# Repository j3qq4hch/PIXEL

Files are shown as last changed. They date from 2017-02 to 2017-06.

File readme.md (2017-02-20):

###PIXEL###
Pixel(yet another) is a dirt cheap 10W LED constant current driver with bells and whistles. 

Two common use scenarios are:

* LED LIGHTING with digital interface(smarthome applications)
* HUGE low-res LED screens with incredible brightness
 
 The device can operate in 2 modes:
 
* As modbus slave device over RS485 non-isolated inteface. This is relative slow mode which can be used for lighting automation systems or stage light control systems.  In this mode device's clock source is external quartz oscillator and it uses UART1 for communication. 
* As shift register. In this mode device operates like three daisy-chained 595 shift registers. In this mode device's clock source is internal RC(as frequency precision is not needed) and pins PF0 PF1 are used as GPIO(for LATCH and RESET signals). More, data clock is connected to PA4, data in is PA3, data out is PA9. So, data signal appears to be buffered by MCU. Clock, latch and reset signals are buffered by external ICs, so many PIXELs can be daisy-chained without concersn about bus integrity.  

Distinguishing between these modes is mostly a matter of proper connector selection, I think.  Mode selection may be done by adding solder joint to PA3 or PA9. These pins should be sampled right after MCU reset and one of the modes should be chosen then.

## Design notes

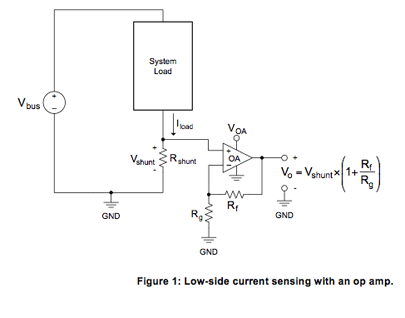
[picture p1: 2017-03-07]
doc/sense2fig1.gif

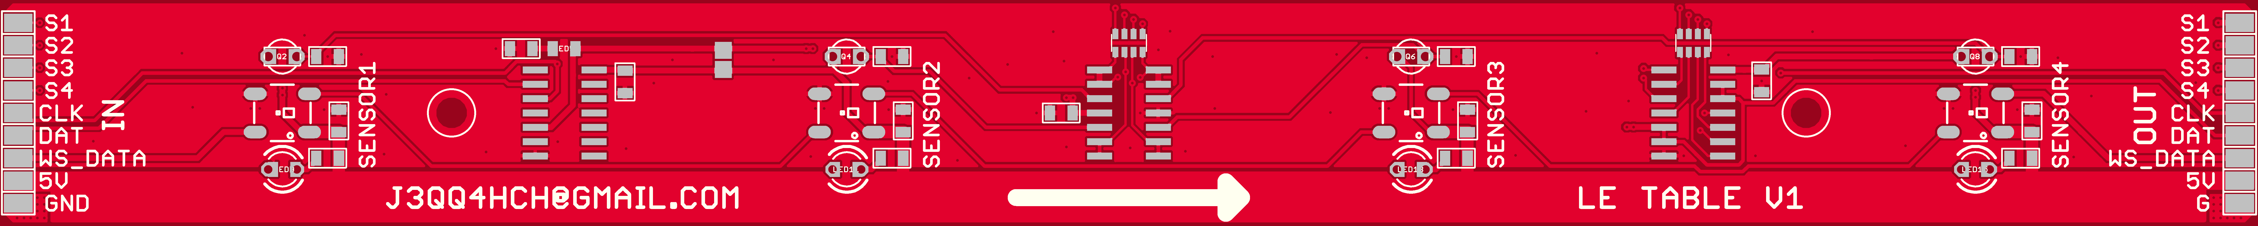
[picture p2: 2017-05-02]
LE table/eagleUp/eagleUp_le_table_board_top.png

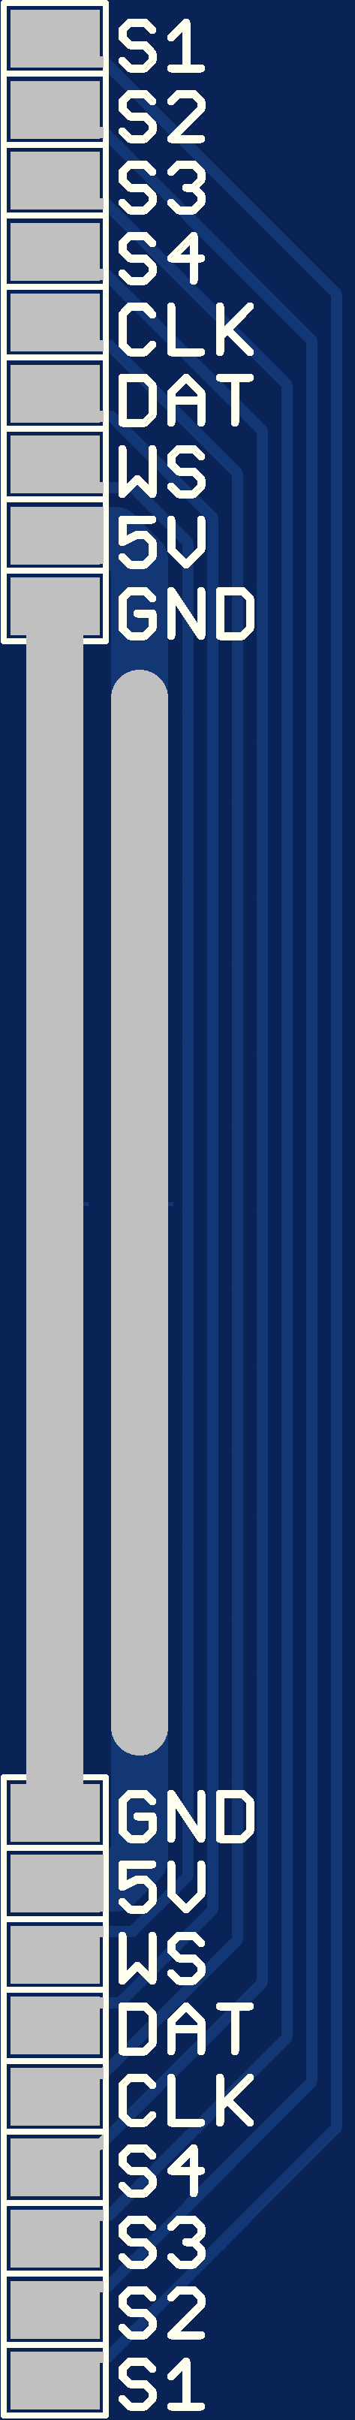
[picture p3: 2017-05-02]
LE table/eagleUp/eagleUp_CONNECTOR_board_top.png

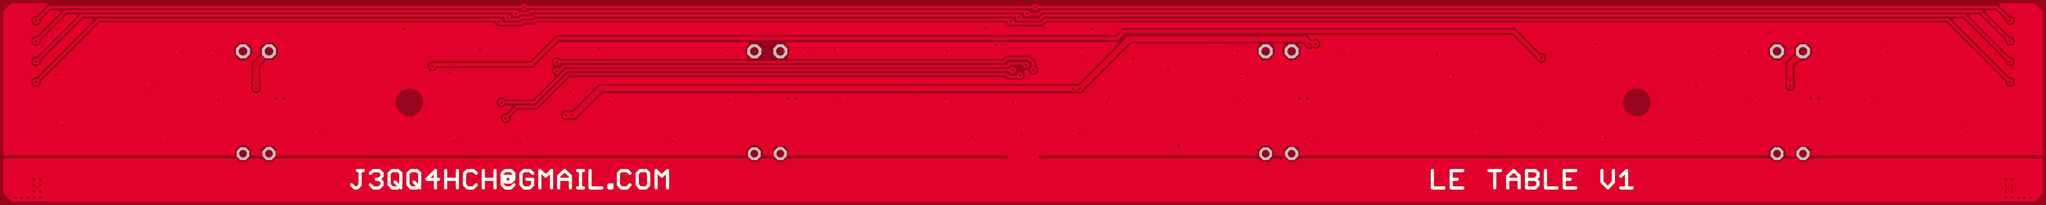
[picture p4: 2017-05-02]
LE table/eagleUp/eagleUp_le_table_board_bottom.png

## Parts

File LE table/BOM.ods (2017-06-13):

Qty | Value | Device | Package | Parts | Description | BOM | DIGIKEY# | FARNELL# | LINK | MANF | MANF# | PACKAGE | TME#
14 | 100 nF | C-0805 | C0805 | C1, C2, C3, C4, C9, C10, C11 |  |  |  | 2496834 |  |  |  | 805 | GRM188R71H104KA93D
8 | 15-24K | R-0805 | R0805 | R1, R2, R3, R4 |  |  |  |  |  |  |  | 805
10 | 150R | R-0805 | R0805 | R6, R9, R10, R11, R12 |  |  |  |  |  |  |  | 805
2 | 150R | RESISTOR_ARRAY | CAT16-J4 | RN2 | Chip Resistor Array 4 Single Resistor
2 | 2N7002 (https://www.chipdip.ru/product/2n7002-2) | 2N7002 (https://www.chipdip.ru/product/2n7002-2) | SOT23B-3 | Q9 |  |  | IRLML2502PBFTR-ND |  |  | Infineon Technologies | IRLML2502TRPBF
2 | LM2902DT | LM2902DT | SO-14 | IC1 |  |  |  |  | https://www.chipdip.ru/product/lm2902dt-2
2 | M74HCT74 | M74HCT74 | SO-14 | IC3 |  |  |  |  | https://www.chipdip.ru/product/m74hct74rm1
2 | CD4066 | CD4066 | SO-14 | IC2 |  |  |  |  | https://www.chipdip.ru/product/cd4066bm
8 | WS2812B | WS2812B | WS2812B | LED1, LED2, LED3, LED4
8 | LED-0805 | LED-0805 | 1206 LED | LED9, LED11, LED13, LED15 | IR led |  |  |  |  |  |  | 805
8 | PHOTOTRANSISTOR-1206 | PHOTOTRANSISTOR-1206 | 1206 | Q2, Q4, Q6, Q8

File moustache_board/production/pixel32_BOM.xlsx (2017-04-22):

Qty | Value | Parts | Description | Package | Manufacturer | Manufacturer part number | Chip & Dip | DigiKey | Farnell | TME
2 | 10 pF | C19, C20 | SMD Capacitor, ± 5%, C0G / NP0 | 0603 | Any | Any |  |  | 1414601 | GRM1885C1H100JA01D
1 | 10 nF | C15 | SMD Capacitor, ± 10%, 6.3V or greater | 0603 | Any | Any |  |  | 2496827 | C0603C103K3RAC
10 | 100 nF | C13, C17, C18, C21, C23, C24, C26, C103, C203, C303 | SMD Capacitor, ± 10%, 50V or greater | 0603 | Any | Any |  |  | 2496834 | GRM188R71H104KA93D
2 | 100 nF | C5, C6 | SMD Capacitor, ± 10%, 50V or greater | 0805 | Any | Any |  |  | 499687
1 | 1 uF | C14 | SMD Capacitor, ± 10%, 6.3V or greater | 0603 | Any | Any |  |  | 2496917 | GRM188R61C105KA93D
3 | 1 uF | C102, C202, C302 | SMD Capacitor, ± 10%, 50V or greater | 0805 | Any | Any |  |  | 1735541 | GRM21BR71H105KA12K
4 | 4.7 uF | C3, C4, C16 | SMD Capacitor, ± 10%, 6.3V or greater | 0603 | Any | Any |  |  | 2496930 | GRM188R60J475KE19D
4 | 10 uF | C101, C201, C301 | SMD Capacitor, ± 10%, 50V or greater | 1812 | Any | Any |  |  | 2449143 | CL32B106KBJNNNE
3 | 2R | R102, R202, R302 | SMD Chip Resistor, ±1%, 250 mW | 1206 | Any | Any |  |  | 2328120 | RC1206FR-072R
6 | 22R | R101, R103, R201, R203, R301, R303 | SMD Chip Resistor, ±1% | 0603 | Any | Any |  |  | 2302996 | CRCW060322R0FKEA
2 | 100R | R11, R12 | SMD Chip Resistor, ±1% | 0603 | Any | Any |  |  | 2303059 | RC0603FR-07100R
1 | 120R | R5 | SMD Chip Resistor, ±1% | 0603 | Any | Any |  |  | 2303067 | CRCW0603120RFKTABC
2 | 1K | R6, R39 | SMD Chip Resistor, ±1% | 0603 | Any | Any |  |  | 2303145 | RC0603FR-071K
1 | 1K6 | R7 | SMD Chip Resistor, ±1% | 0603 | Any | Any |  |  | 2303159 | RC0603FR-071K6
6 | 10K | R3, R8, R9, R13, R14, R15 | SMD Chip Resistor, ±1% | 0603 | Any | Any |  |  | 2008341 | RC0603FR-0710K
1 | 100K | R10 | SMD Chip Resistor, ±1% | 0603 | Any | Any |  |  | 2303232 | RC0603FR-07100K
1 | 115K | R2 of MODULE1 | SMD Chip Resistor, ±1% | 0603 | Any | Any |  |  | 2303234 | N/A
2 | 510R | RN1, RN2 | Chip Resistor Array 4 Single Resistor | CAT16-J4 | Bourns Inc | CAT16-511J4LF | 9000044911 | CAT16-511J4LF-ND | 2321730 | N/A
3 | 47 uH | L102, L202, L302 | Unshielded Wirewound Inductor, 1 A RMS max, 1.6 A saturation, 0.2 ohm | SDR0805 | Bourns Inc | SDR0805-470KL | 8980699057 | SDR0805-470KLCT-ND | 1828030 | N/A
1 | 16MHz | Y1 | SMD Crystal, 10 ppm, 9 pF | 3.2X2.5 | Epson | X1E0000210013 TSX-3225 16 MHZ 9.0PF | 8596067027 | SER4069CT-ND | 1712841 | N/A
1 | LED-0603 | LED2 | SMD LED, Green, 20 mA, 2.1 V | LED0603 | Lite-On Inc | LTST-C191KGKT | 8598509892 | 160-1446-1-ND | 2293494 | LTST-C191KGKT
3 | DIODE-SOD123 | D101, D201, D301 | Schottky Rectifier, 100 V, 1 A | SOD123 | ON Semiconductor | MBRS1100T3G | MBRS1100T3G | MBRS1100T3GOSCT-ND | 9555862 | MBRS1100T3G
1 | SMF05C | D1 | 5 TVS Diode Array, Unidirectional, 5V Vrwm, 12.5 Vc Max | SC70_6L | Semtech Corporation | SMF05C.TCT | 9000048448 | SMF05CCT-ND | 2059033 | SMF05CT1G
1 | TVS_DIODE-SMB | D5 | TVS Diode, Unidirectional, 26V Vrwm, 53.5 Vc Max | SMB | STMicroelectronics | SMBJ26CA | 8023193826 | 497-15658-2-ND | 1749366 | SMBJ26CA-LF
3 | N-FET-SOT23 | Q101, Q201, Q301 | MOSFET Transistor, N Channel, 3.6 A, 40 V, 0.044 ohm | SOT23-3 | Infineon Technologies | IRLML0040TRPBF | 9000095041 | IRLML0040TRPBFCT-ND | 1831088 | IRLML0040TRPBF
1 | GW1584 | MODULE1 | http://mysku.ru/blog/aliexpress/35938.html | GW1584 | Unknown | GW1584 | N/A | N/A | N/A | N/A
3 | IRS44273L | IC101, IC201, IC301 | Low-Side Gate Driver IC Non-Inverting SOT-23-5 | SOT23-5 | Infineon Technologies | IRS44273LTRPBF | 9000204261 | IRS44273LTRPBFTR-ND | 2580779 | IRS44273LTRPBF
1 | STM32F030K6TX-LQFP32(7X7) | IC1 | ARM® Cortex®-M0 STM32 F0 Microcontroller IC 32-Bit 48MHz 32KB (32K x 8) FLASH | LQFP32 | STMicroelectronics | STM32F030K6T6 | 9000250493 | 497-14046-ND | 2432085 | STM32F030K6T6
1 | ST3485SOIC8 | IC3 | 1/1 Transceiver Half RS422, RS485 | SOIC8 | STMicroelectronics | ST3485EBDR | 9000220421 | 497-2080-1-ND | 2253266 | ST3485EBD
2 | MC74VHC1GT125 | IC6, IC7 | Buffer, Non-Inverting 1 Element 1 Bit per Element Push-Pull Output | SOT23-5 | ON Semiconductor | MC74VHC1GT125 | 9000014391 | MC74VHC1GT125DT1GOSDKR-ND | 2101847 | N/A
1 | LM317 | IC8 | Linear Voltage Regulator IC Positive Adjustable Output 1.25 V ~ 37 V 1.5A | SOT223 | Texas Instruments | LM317MSTT3G | LM317DCY | 296-23224-5-ND | 2112605 | LM317DCY
2 | B7B-PH-K-S-SIDE | CON1, CON2 | 7 Positions Header Connector, Through Hole | 2.00 mm x 7 | JST or Confly | B7B-PH-K-S(LF)(SN) or DS1066-08M(MW-8M) | 9000325604 | 455-1709-ND | 9491864 | B7B-PH-K-S
2 | PINHEAD_1X02-2.54 | СON3 | pinheader 2P | 1X02-PTH-2.54 | Any

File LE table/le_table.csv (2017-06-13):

Qty | Value | Device | Package | Parts | Description | BOM | DIGIKEY# | FARNELL# | LINK | MANF | MANF# | PACKAGE | TME#
2 |  | SOLDER_JOINT | RES_0 | SJ1, SJ2
7 | 100 nF | C-0805 | C0805 | C1, C2, C3, C4, C9, C10, C11 |  |  |  | 2496834 |  |  |  | 0805 | GRM188R71H104KA93D
4 | 15-20K | R-0805 | R0805 | R1, R2, R3, R4 |  |  |  |  |  |  |  | 0805
5 | 150R | R-0805 | R0805 | R6, R9, R10, R11, R12 |  |  |  |  |  |  |  | 0805
1 | 150R | RESISTOR_ARRAY | CAT16-J4 | RN2 | Chip Resistor Array 4 Single Resistor
1 | 2K | R-0805 | R0805 | R5 |  |  |  |  |  |  |  | 0805
1 | CD4066 | CD4066 | SO-14 | IC2 |  |  |  |  | https://www.chipdip.ru/product/cd4066bm
3 | CONNECTION | CONNECTION | CONNECTION | U$3, U$6, U$7 |  | EXCLUDE
2 | CONNECTOR | CONNECTOR | CONNECTOR | CON2, CON5 |  | EXCLUDE
1 | IRLML2502-SOT23 | IRLML2502-SOT23 | SOT23B-3 | Q9 | MOSFET N-CH 20V 4.2A SOT-23 |  | IRLML2502PBFTR-ND |  |  | Infineon Technologies | IRLML2502TRPBF
5 | LED-0805 | LED-0805 | 0805_LED | LED5, LED9, LED11, LED13, LED15 |  |  |  |  |  |  |  | 0805
1 | LM2902DT | LM2902DT | SO-14 | IC1 |  |  |  |  | https://www.chipdip.ru/product/lm2902dt-2
1 | M74HCT74 | M74HCT74 | SO-14 | IC3 |  |  |  |  | https://www.chipdip.ru/product/m74hct74rm1
4 | PHOTOTRANSISTOR-0805 | PHOTOTRANSISTOR-0805 | 0805 | Q2, Q4, Q6, Q8
2 | PINHEAD_1X09-2 | PINHEAD_1X09-2 | 1X09-PTH_2 | CON3, CON4 |  | EXCLUDE
4 | WS2812B | WS2812B | WS2812B | LED1, LED2, LED3, LED4

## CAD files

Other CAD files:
LE table/PCB.skp
LE table/connector.skp
LE table/table.skp

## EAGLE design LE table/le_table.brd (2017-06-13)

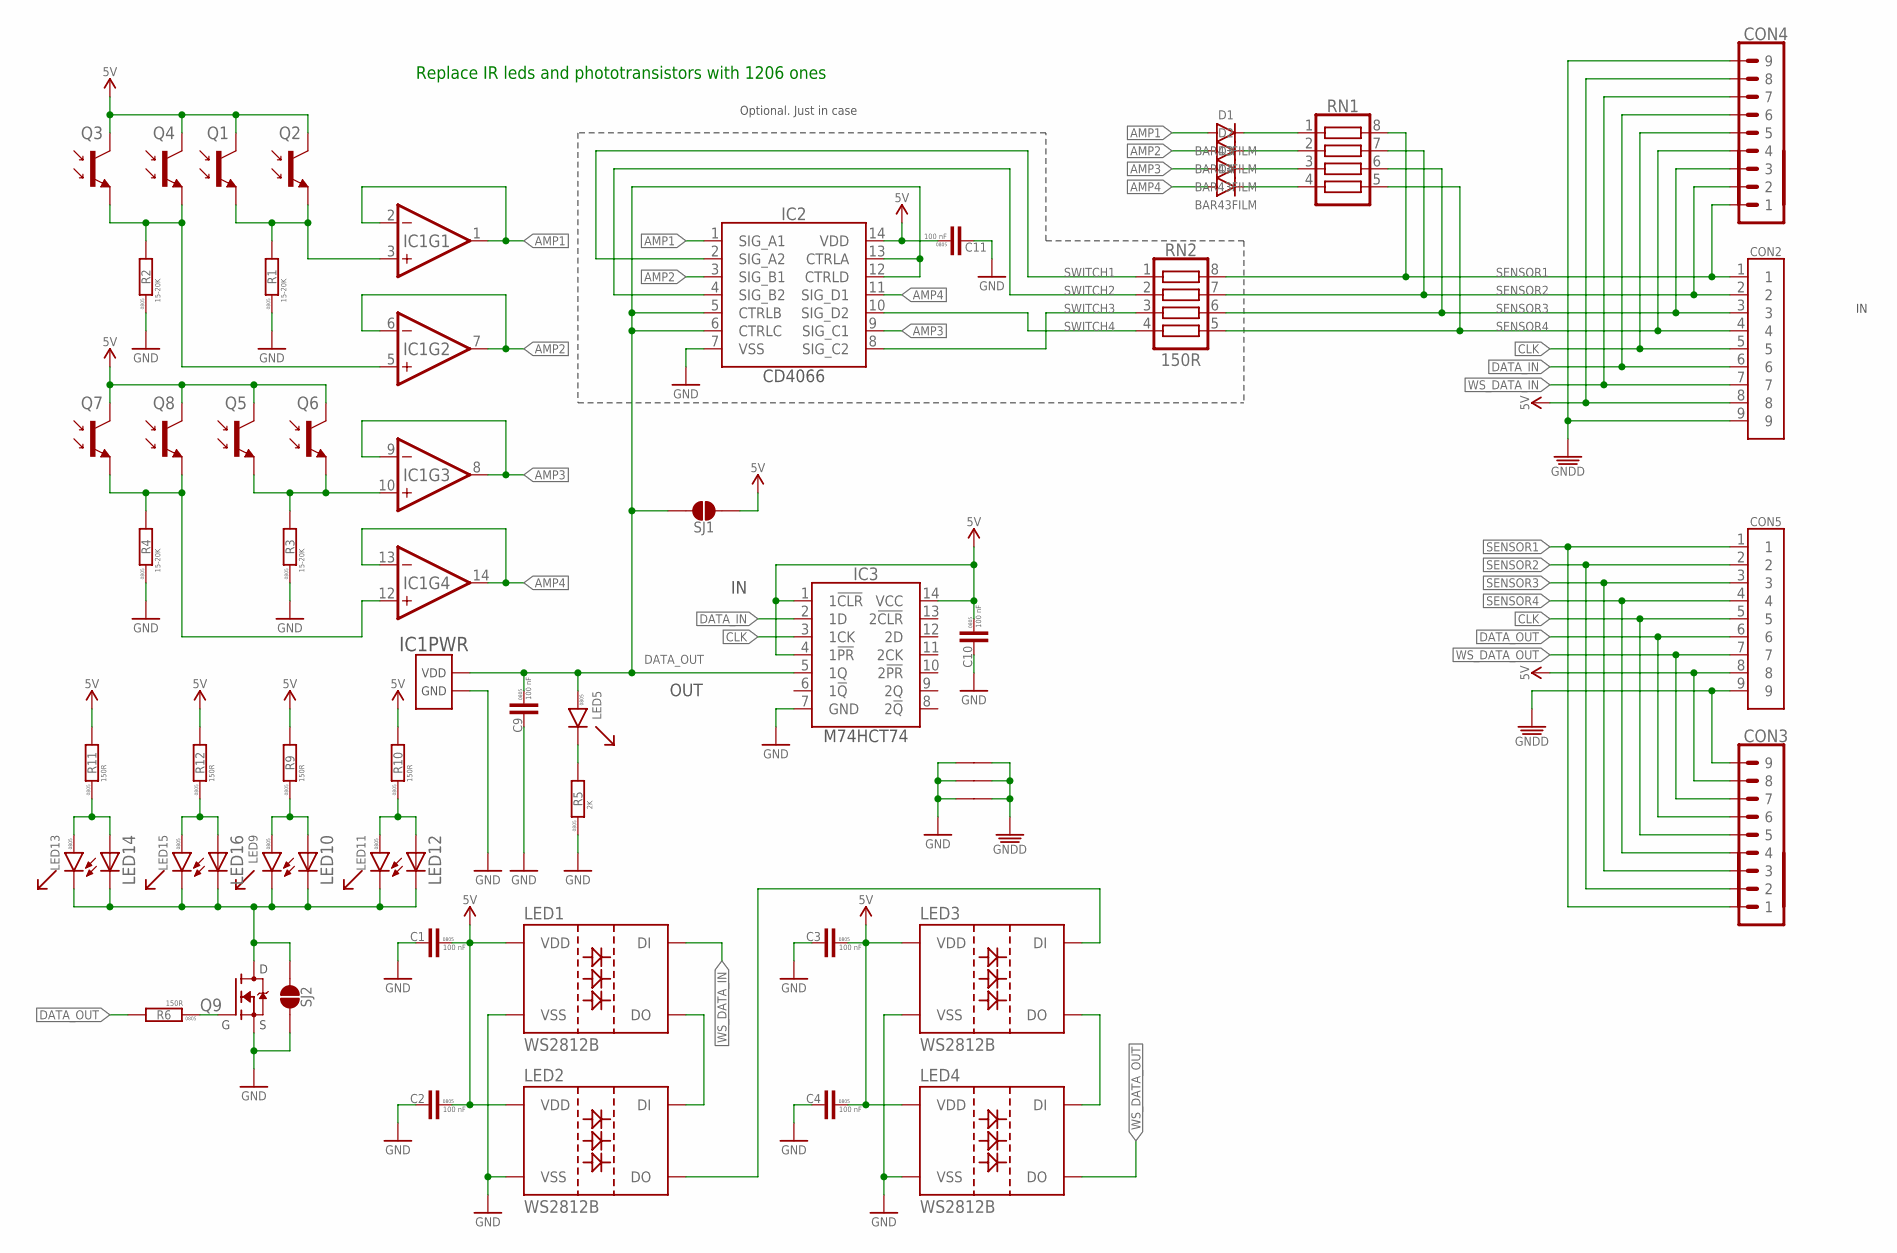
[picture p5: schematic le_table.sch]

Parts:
C1, C2, C3, C4, C9, C10, C11: 100 nF; C0805; FARNELL# 2496834
CON2, CON5: CONNECTOR
CON3, CON4: PINHEAD_1X09-2; 1X09-PTH_2
D1, D2, D3, D4: BAR43AFILM; SOT23-3
IC1: LM2902DT; SO-14
IC2: CD4066; SO-14
IC3: M74HCT74; SO-14
LED1, LED2, LED3, LED4: WS2812B
LED5, LED9, LED11, LED13, LED15: LED-0805; 0805_LED
LED10, LED12, LED14, LED16: LED-3MM
Q1, Q3, Q5, Q7: PHOTOTRANSISTOR-3MM; LED-3MM
Q2, Q4, Q6, Q8: PHOTOTRANSISTOR-0805; 0805
Q9: IRLML2502-SOT23; SOT23B-3
R1, R2, R3, R4: 15-20K; R0805
R5: 2K; R0805
R6, R9, R10, R11, R12: 150R; R0805
RN1: RESISTOR_ARRAY; CAT16-J4
RN2: 150R; CAT16-J4
SJ1, SJ2: SOLDER_JOINT; RES_0
U$3, U$6, U$7: CONNECTION

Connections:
AMP1: D1.1 (A), IC1.1 (OUT), IC1.2 (-IN), IC2.1 (SIG_A1)
AMP2: D2.1 (A), IC1.6 (-IN), IC1.7 (OUT), IC2.3 (SIG_B1)
AMP3: D3.1 (A), IC1.8 (OUT), IC1.9 (-IN), IC2.9 (SIG_C1)
AMP4: D4.1 (A), IC1.13 (-IN), IC1.14 (OUT), IC2.11 (SIG_D1)
CLK: CON2.5, CON3.5, CON4.5, CON5.5, IC3.3 (1CK)
DATA_IN: CON2.6, CON4.6, IC3.2 (1D)
DATA_OUT: C9.1, CON3.6, CON5.6, IC1.4 (VDD), IC2.5 (CTRLB), IC2.6 (CTRLC), IC2.12 (CTRLD), IC2.13 (CTRLA), IC3.5 (1Q), LED5.A, R6.2, SJ1.2
GND: C1.2, C2.2, C3.2, C4.2, C9.2, C10.2, C11.2, IC1.11 (GND), IC2.7 (VSS), IC3.7 (GND), LED1.3 (VSS), LED2.3 (VSS), LED3.3 (VSS), LED4.3 (VSS), Q9.2 (S), R1.1, R2.1, R3.1, R4.1, R5.1, SJ2.2, U$3.P$2, U$6.P$2, U$7.P$2
GNDD: CON2.9, CON3.9, CON4.9, CON5.9, U$3.P$1, U$6.P$1, U$7.P$1
unnamed: Q9.1 (G), R6.1
unnamed: LED5.C, R5.2
unnamed: LED1.2 (DO), LED2.4 (DI)
unnamed: LED2.2 (DO), LED3.4 (DI)
unnamed: LED3.2 (DO), LED4.4 (DI)
unnamed: LED11.A, LED12.A, R10.1
unnamed: LED13.A, LED14.A, R11.1
unnamed: LED9.A, LED10.A, R9.1
unnamed: LED15.A, LED16.A, R12.1
unnamed: D1.3 (C), RN1.1
unnamed: D2.3 (C), RN1.2
unnamed: D3.3 (C), RN1.3
unnamed: D4.3 (C), RN1.4
unnamed: LED9.C, LED10.K (C), LED11.C, LED12.K (C), LED13.C, LED14.K (C), LED15.C, LED16.K (C), Q9.3 (D), SJ2.1
SENS1: IC1.3 (+IN), Q1.K (E), Q2.2 (E), R1.2
SENS2: IC1.5 (+IN), Q3.K (E), Q4.2 (E), R2.2
SENS3: IC1.10 (+IN), Q5.K (E), Q6.2 (E), R3.2
SENS4: IC1.12 (+IN), Q7.K (E), Q8.2 (E), R4.2
SENSOR1: CON2.1, CON3.1, CON4.1, CON5.1, RN1.8, RN2.8
SENSOR2: CON2.2, CON3.2, CON4.2, CON5.2, RN1.7, RN2.7
SENSOR3: CON2.3, CON3.3, CON4.3, CON5.3, RN1.6, RN2.6
SENSOR4: CON2.4, CON3.4, CON4.4, CON5.4, RN1.5, RN2.5
SWITCH1: IC2.2 (SIG_A2), RN2.1
SWITCH2: IC2.4 (SIG_B2), RN2.2
SWITCH3: IC2.8 (SIG_C2), RN2.3
SWITCH4: IC2.10 (SIG_D2), RN2.4
VDD_5V: C1.1, C2.1, C3.1, C4.1, C10.1, C11.1, CON2.8, CON3.8, CON4.8, CON5.8, IC2.14 (VDD), IC3.1 (1!CLR), IC3.4 (1!PR), IC3.14 (VCC), LED1.1 (VDD), LED2.1 (VDD), LED3.1 (VDD), LED4.1 (VDD), Q1.A (C), Q2.1 (C), Q3.A (C), Q4.1 (C), Q5.A (C), Q6.1 (C), Q7.A (C), Q8.1 (C), R9.2, R10.2, R11.2, R12.2, SJ1.1
WS_DATA_IN: CON2.7, CON4.7, LED1.4 (DI)
WS_DATA_OUT: CON3.7, CON5.7, LED4.2 (DO)

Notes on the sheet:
OUT
Optional. Just in case
Replace IR leds and phototransistors with 1206 ones

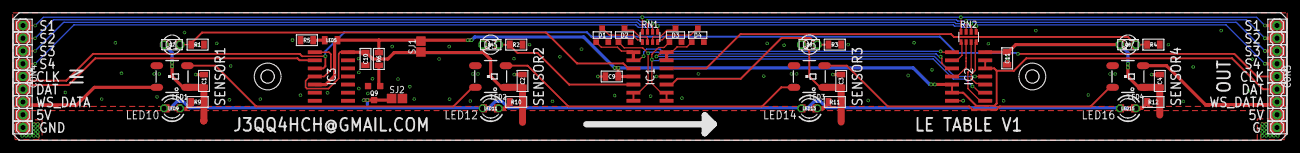
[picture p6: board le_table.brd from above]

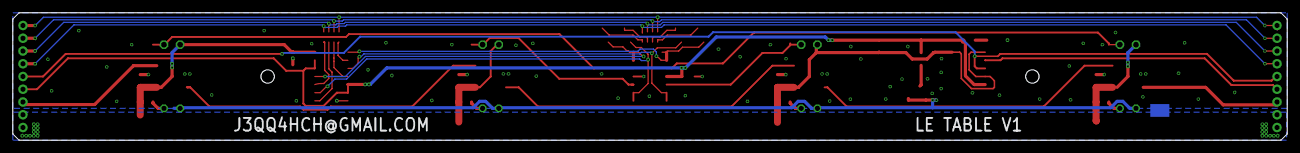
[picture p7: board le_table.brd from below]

Board: 2 copper layers, 200.0 x 20.0 mm, 59 parts (3 on the bottom side), 38 nets.

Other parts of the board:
U$1, U$4: MOUNTING_HOLE_M2

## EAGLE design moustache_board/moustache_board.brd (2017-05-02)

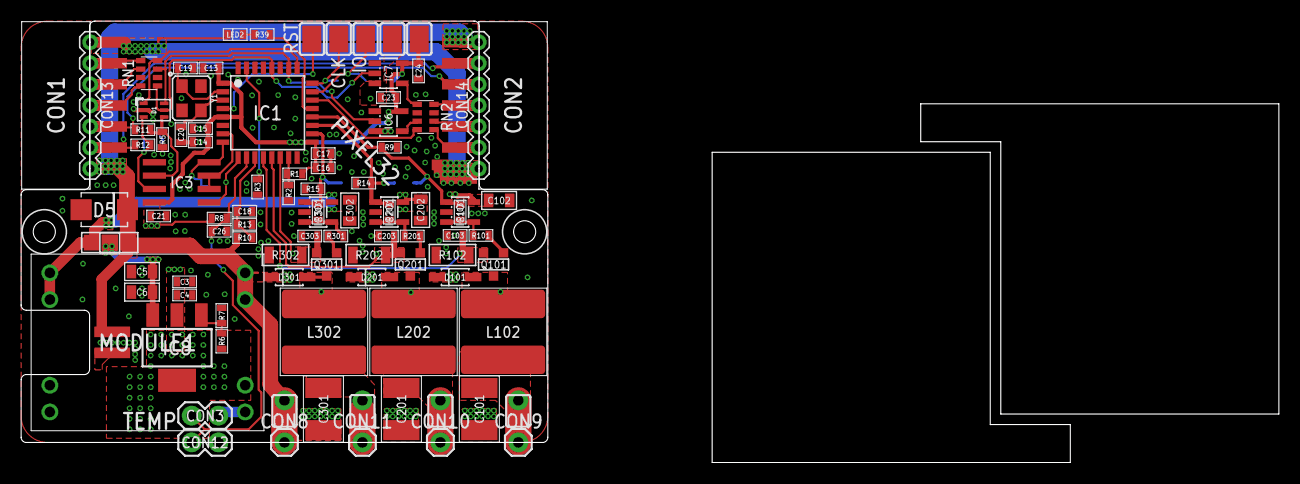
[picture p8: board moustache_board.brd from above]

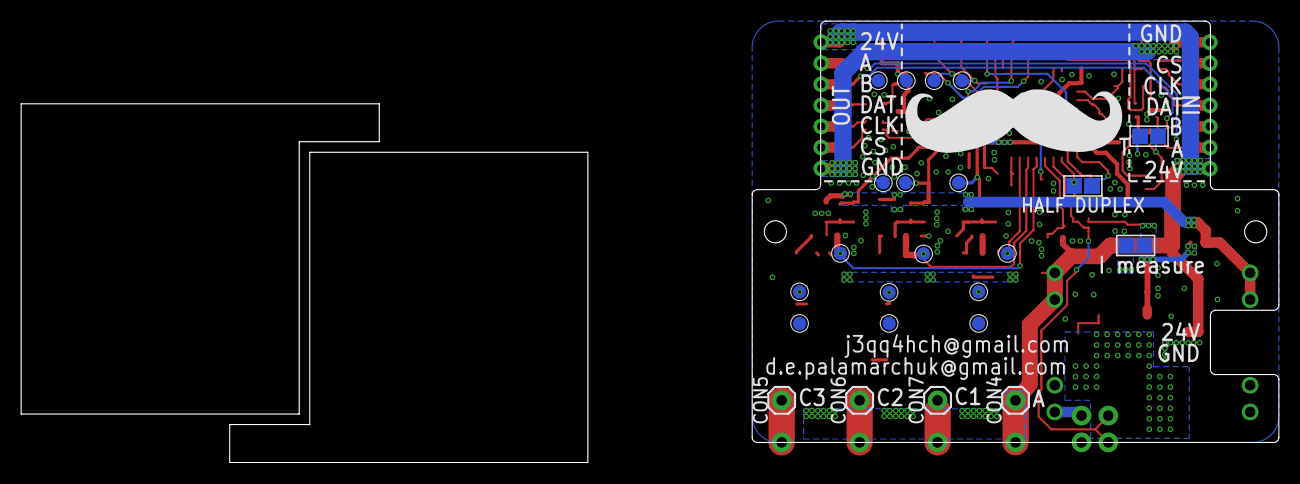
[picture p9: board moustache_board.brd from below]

Board: 2 copper layers, 50.0 x 40.0 mm, 129 parts (24 on the bottom side), 57 nets.

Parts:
C3, C4, C16: 4.7 uF; C0603
C5, C6: 100 nF; C0805
C13, C17, C18, C21, C23, C24, C26, C103, C203, C303: 100 nF; C0603
C14: 1 uF; C0603
C15: 10 nF; C0603
C19, C20: 10 pF; C0603
C101, C201, C301: 10 uF; C1812
C102, C202, C302: 1 uF; C0805
CON1, CON2: B7B-PH-K-S-SIDE; B7B-PH-K-S_SIDE
CON3, CON12: PINHEAD_1X02-2.54; 1X02-PTH-2.54
CON4, CON5, CON6, CON7, CON8, CON9, CON10, CON11: PINHEAD_1X01-2.54; 1X01-PTH-2.54
CON13, CON14: PINHEAD_1X07-2; 1X07-PTH-2
CON15: B2B-PH-K-S_SIDE_MOUNT
D1: SMF05C; SC70_6L
D5: TVS_DIODE-SMB; SMB
D101, D201, D301: DIODE-SOD123; SOD123
DRILEGEND: DRILEGEND
IC1: STM32F030K6TX-LQFP32(7X7); LQFP32-7X7
IC3: ST3485SOIC8; SOIC8
IC6, IC7: MC74VHC1GT125; SOT23-5
IC8: LM317; SOT223
IC101, IC201, IC301: IRS44273L; SOT23-5
L102, L202, L302: 47UH; SDR0805
LED2: LED-0603; LED0603
LED_ANODE: WIREPADSMD2.5-1.8; PAD-2.5-1.8
LED_CATHODE1, LED_CATHODE2, LED_CATHODE3: WIREPADSMD2.5-1.8; PAD-2.5-1.8
MODULE1: GW1584
PAD1, PAD2, PAD3, PAD4, PAD5: WIREPADSMD2.5-1.8; PAD-2.5-1.8
Q101, Q201, Q301: N-FET-SOT23; SOT23-3
R1, R2, R11, R12: 100R; R0603
R3, R8, R9, R13, R14, R15: 10K; R0603
R5: 120R; R0603
R6, R39: 1K; R0603
R7: 1K6; R0603
R10: 100K; R0603
R101, R103, R201, R203, R301, R303: 22R; R0603
R102, R202, R302: 2R; R1206
RN1, RN2: 510R; CAT16-J4
SJ1, SJ2, SJ3, SJ4, SJ5: RES_0
TP1, TP2, TP3, TP4, TP101, TP102, TP103, TP104, TP201, TP202, TP203, TP204, TP301, TP302, TP303, TP304: PAD.05; PAD.05X.05
U$2: BOARD_OUTLINE
U$3, U$6, U$7, U$8, U$9, U$10: CONNECTION
U$4, U$5: MOUNTING_HOLE_M2
U$11: MOUSTACHE2
Y1: 16MHz; OSCILLATOR-3.2X2.5

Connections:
A: D1.4, IC3.6, R5.2, R11.1
B: D1.3, IC3.7, R12.1, SJ2.1
CLOCK: D1.6, IC1.26, IC6.2, RN1.3
CLOCK_BUFFERED: IC6.4, RN2.3
CS: D1.1, IC1.25, RN1.4
CS_OUT: IC1.22, RN2.4
DATA_BUFFERED: IC7.4, RN2.1
GND: C3.1, C4.1, C5.1, C6.1, C13.1, C14.1, C15.1, C16.1, C17.1, C18.1, C19.2, C20.2, C21.1, C23.1, C24.1, C26.1, C102.1, C103.1, C202.1, C203.1, C302.1, C303.1, CON3.1, CON12.1, CON15.1, D1.2, D5.A, IC1.16, IC1.32, IC3.5, IC6.3, IC7.3, IC101.2, IC201.2, IC301.2, MODULE1.IN-@1, MODULE1.IN-@2, MODULE1.OUT-@1, MODULE1.OUT-@2, PAD4.P$1, R2.2, R3.2, R7.1, R9.1, R13.1, R14.1, R15.1, R102.P$1, R202.P$1, R302.P$1, TP2.P$1, TP104.P$1, TP204.P$1, TP304.P$1, U$3.P$2, U$6.P$2, U$7.P$2, U$8.P$2, U$9.P$2, U$10.P$2, Y1.2, Y1.4
GNDD: CON1.7, CON2.7, CON13.1, CON14.1, LED2.C, U$3.P$1, U$6.P$1, U$7.P$1, U$8.P$1, U$9.P$1, U$10.P$1
LED1_CURRENT: C103.2, IC1.12, Q101.2, R102.P$2, TP103.P$1
LED1_PWM: IC1.20, IC101.1, R9.2, R103.1, TP101.P$1
LED2_CURRENT: C203.2, IC1.13, Q201.2, R202.P$2, TP203.P$1
LED2_PWM: IC1.19, IC201.1, R14.2, R203.1, TP201.P$1
LED3_CURRENT: C303.2, IC1.14, Q301.2, R302.P$2, TP303.P$1
LED3_PWM: IC1.18, IC301.1, R15.2, R303.1, TP301.P$1
LED_DRIVER1:N$2: D101.A, L102.1, Q101.3, TP102.P$1
LED_DRIVER1:N$3: IC101.3, IC101.4, R101.1, R103.2
LED_DRIVER1:N$7: Q101.1, R101.2
LED_DRIVER2:N$2: D201.A, L202.1, Q201.3, TP202.P$1
LED_DRIVER2:N$3: IC201.3, IC201.4, R201.1, R203.2
LED_DRIVER2:N$7: Q201.1, R201.2
LED_DRIVER3:N$2: D301.A, L302.1, Q301.3, TP302.P$1
LED_DRIVER3:N$3: IC301.3, IC301.4, R301.1, R303.2
LED_DRIVER3:N$7: Q301.1, R301.2
MOSI/DATA: D1.5, IC1.28, IC7.2, RN1.1
unnamed: R5.1, SJ2.2
unnamed: C3.2, C4.2, IC8.2, IC8.4, R6.2, SJ4.2
unnamed: IC1.15, R1.1, R2.1
unnamed: C19.1, IC1.2, Y1.1
unnamed: C5.2, C6.2, IC8.3, SJ1.2, SJ3.2
unnamed: IC1.31, R3.1
unnamed: C20.1, IC1.3, Y1.3
unnamed: C101.P$1, CON5.1, CON9.1, L102.2, LED_CATHODE1.P$1
unnamed: CON1.4, CON13.4, RN1.8
unnamed: CON1.5, CON13.3, RN1.6
unnamed: CON1.6, CON13.2, RN1.5
unnamed: CON2.4, CON14.4, RN2.8
unnamed: CON2.5, CON14.3, RN2.6
unnamed: CON2.6, CON14.2, RN2.5
unnamed: IC8.1, R6.1, R7.2
unnamed: C201.P$1, CON6.1, CON10.1, L202.2, LED_CATHODE2.P$1
unnamed: LED2.A, R39.1
unnamed: C301.P$1, CON7.1, CON11.1, L302.2, LED_CATHODE3.P$1
RE/DE: IC1.7, IC3.2, IC3.3
RS485_A: CON1.2, CON2.2, CON13.6, CON14.6, R12.2
RS485_B: CON1.3, CON2.3, CON13.5, CON14.5, R11.2
RST: IC1.4, PAD5.P$1
RX: IC1.9, IC3.1, SJ5.2
STAT_LED: IC1.21, R39.2
SWCLK: IC1.24, PAD1.P$1, TP4.P$1
SWIO: IC1.23, PAD2.P$1, TP1.P$1
TEMP: C26.2, CON3.2, CON12.2, IC1.10, R8.1
TX: IC1.8, IC3.4, SJ5.1
VDD_3V3: C13.2, C14.2, C15.2, C16.2, C17.2, C21.2, C23.2, C24.2, IC1.1, IC1.5, IC1.17, IC3.8, IC6.5, IC7.5, PAD3.P$1, R1.2, R8.2, SJ4.1, TP3.P$1
VDD_12V: C102.2, C202.2, C302.2, IC101.5, IC201.5, IC301.5, MODULE1.OUT+@1, MODULE1.OUT+@2, SJ1.1
VDD_24V: C101.P$2, C201.P$2, C301.P$2, CON1.1, CON2.1, CON4.1, CON8.1, CON13.7, CON14.7, CON15.2, D5.C, D101.C, D201.C, D301.C, LED_ANODE.P$1, MODULE1.IN+@1, MODULE1.IN+@2, R10.1, SJ3.1
VIN_SENSE: C18.2, IC1.11, R10.2, R13.2

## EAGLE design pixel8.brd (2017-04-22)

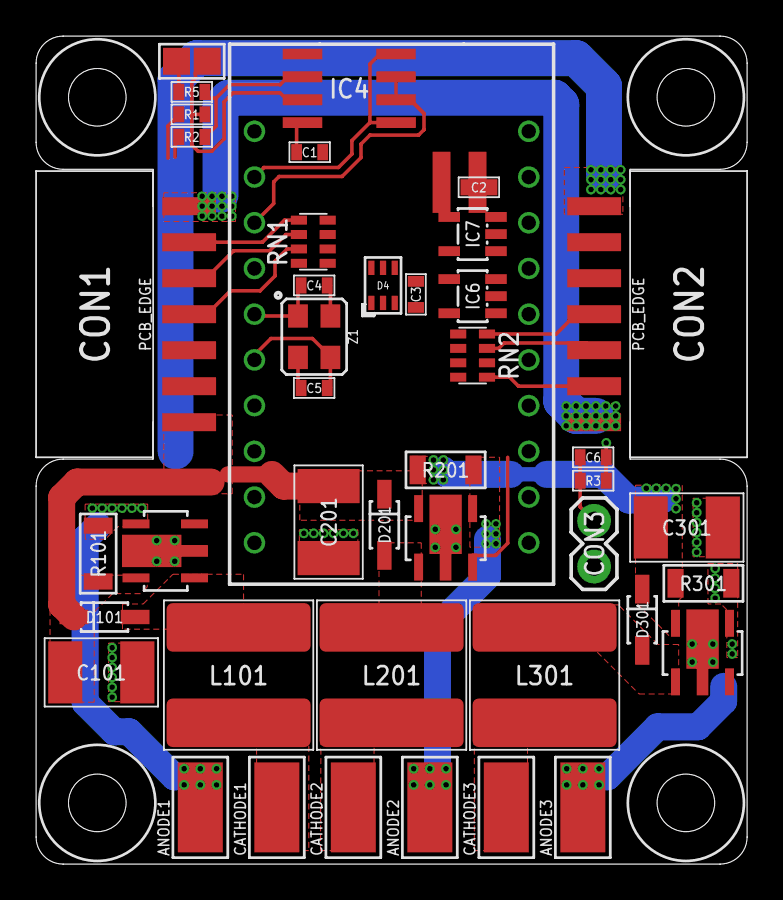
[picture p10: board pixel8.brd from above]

Board: 2 copper layers, 39.5 x 46.0 mm, 50 parts (1 on the bottom side), 38 nets.

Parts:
ANODE1, ANODE2, ANODE3: WIREPADSMD5-2,5; 5-2,5
C1: 0.1uF; C0603
C2, C3, C6: 100 nF; C0603
C4, C5: C0603
C101, C201, C301: 10 uF; C1812
CATHODE1, CATHODE2, CATHODE3: WIREPADSMD5-2,5; 5-2,5
CON1, CON2: DS1066-07M-SIDE; DS1066-08M_SIDE
CON3: PINHEAD_1X02-2.54; 1X02-PTH-2.54
CON15: B2B-PH-K-S_SIDE_MOUNT
D4: SMF05C; SC70_6L
D101, D201, D301: CRS08-SOD123; SOD123
IC4: ST3485SOIC8; SOIC8
IC6, IC7: MC74VHC1GT125; SOT23-5
IC101, IC201, IC301: PT4115
L101, L201, L301: 47UH; SDR0805
MODULE1: STM8S_MIN_DEV_BOARD; STM8_MIN_DEV_BOARD
R1, R2: 100R; R0603
R3: 10K; R0603
R5: 120R; R0603
R101, R201, R301: R1206
RN1, RN2: 510R; CAT16-J4
SJ2: RES_0
U$1: PIXEL8_BOARD_OUTLINE
U$2, U$3, U$4, U$5: MOUNTING_HOLE_M3
U$6: CONNECTION
Z1: 16MHz; OSCILLATOR-3.2X2.5

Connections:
A: D4.4, IC4.6, R2.1, R5.2
A1: ANODE1.1, IC101.4, R101.P$1
A2: ANODE2.1, IC201.4, R201.P$1
A3: ANODE3.1, IC301.4, R301.P$1
B: D4.3, IC4.7, R1.1, SJ2.1
C1: CATHODE1.1, L101.2
C2: CATHODE2.1, L201.2
C3: CATHODE3.1, L301.2
CLOCK: D4.6, IC6.2, MODULE1.15, RN1.3
CLOCK_BUFFERED: IC6.4, RN2.2
CS: D4.1, MODULE1.10, RN1.4
CS_OUT: MODULE1.13, RN2.4
DATA_BUFFERED: IC7.4, RN2.1
GND: C1.1, C2.1, C3.1, C4.2, C5.2, C6.1, C101.P$1, C201.P$1, C301.P$1, CON15.1, D4.2, IC4.5, IC6.3, IC7.3, IC101.2, IC101.2A, IC201.2, IC201.2A, IC301.2, IC301.2A, MODULE1.7, R3.1, U$6.P$2, Z1.2, Z1.4
GNDD: CON1.7, CON2.7, U$6.P$1
LED_DRV1:SW: D101.A, IC101.1, L101.1
LED_DRV2:SW: D201.A, IC201.1, L201.1
LED_DRV3:SW: D301.A, IC301.1, L301.1
MOSI/DATA: D4.5, IC7.2, MODULE1.16, RN1.2
unnamed: CON2.4, RN2.8
unnamed: CON2.6, RN2.5
unnamed: R5.1, SJ2.2
unnamed: C4.1, MODULE1.5, Z1.1
unnamed: C5.1, MODULE1.6, Z1.3
unnamed: CON1.4, RN1.7
unnamed: CON1.5, RN1.6
unnamed: CON1.6, RN1.5
unnamed: CON2.5, RN2.7
PWM1: IC101.3, MODULE1.1
PWM2: IC201.3, MODULE1.20
PWM3: IC301.3, MODULE1.19
RE/DE: IC4.2, IC4.3, MODULE1.3
RS485_A: CON1.2, CON2.2, R1.2
RS485_B: CON1.3, CON2.3, R2.2
RX/TX: IC4.1, IC4.4, MODULE1.2
TEMP: C6.2, CON3.1, MODULE1.14, R3.2
VDD_3V3: C1.2, C2.2, C3.2, CON3.2, IC4.8, IC6.5, IC7.5, MODULE1.9
VDD_12V: C101.P$2, C201.P$2, C301.P$2, CON1.1, CON2.1, D101.C, D201.C, D301.C, IC101.5, IC201.5, IC301.5, R101.P$2, R201.P$2, R301.P$2

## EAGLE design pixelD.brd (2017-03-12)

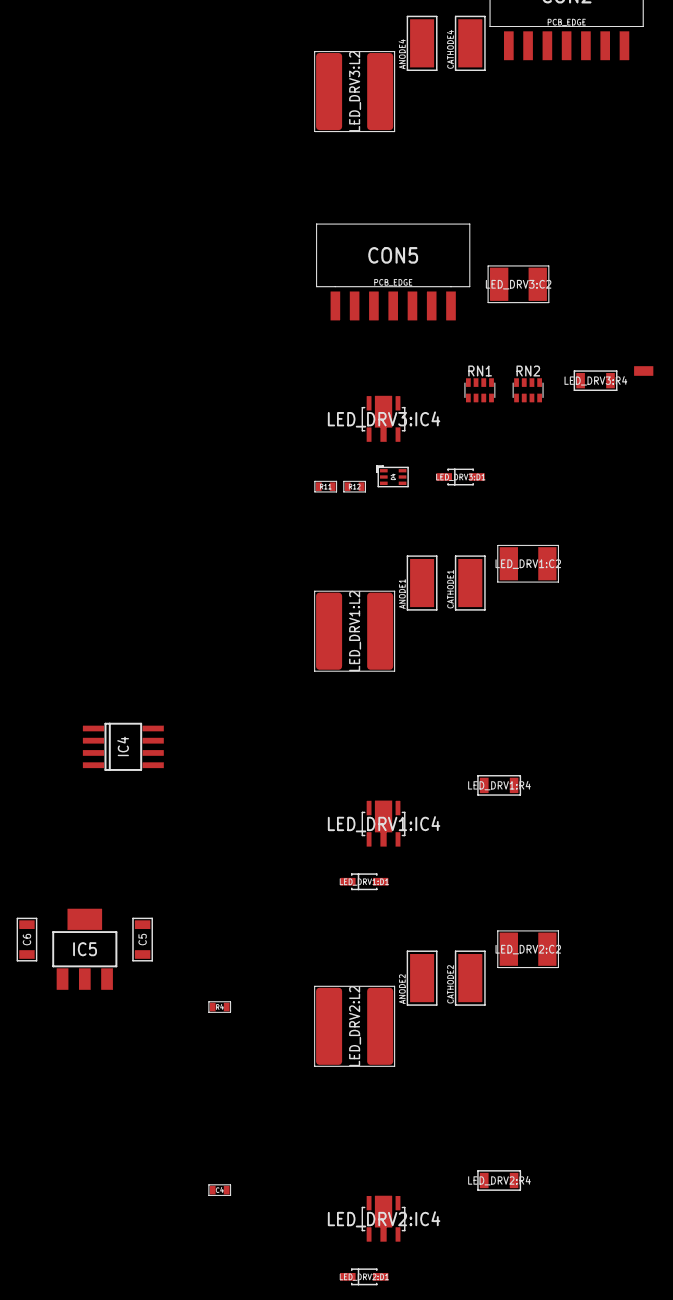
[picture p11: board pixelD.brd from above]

Board: 2 copper layers, 36 parts (1 on the bottom side), 32 nets, no tracks yet.

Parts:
ANODE1, ANODE2, ANODE4: WIREPADSMD5-2,5; 5-2,5
C4: C0603
C5, C6: C1206
CATHODE1, CATHODE2, CATHODE4: WIREPADSMD5-2,5; 5-2,5
CON2, CON5: DS1066-07M-SIDE; DS1066-08M_SIDE
D4: SMF05C; SC70_6L
IC4: WS2811; SOIC8
IC5: LM1117-3.3-SOT223; SOT223
LED_DRV1:C2, LED_DRV2:C2, LED_DRV3:C2: 10 uF; C1812
LED_DRV1:D1, LED_DRV2:D1, LED_DRV3:D1: CRS08-SOD123; SOD123
LED_DRV1:IC4, LED_DRV2:IC4, LED_DRV3:IC4: PT4115
LED_DRV1:L2, LED_DRV2:L2, LED_DRV3:L2: 47UH; SDR0805
LED_DRV1:R4, LED_DRV2:R4, LED_DRV3:R4: R1206
R4, R11, R12: 100R; R0603
R6: RES_0
RN1, RN2: 510R; CAT16-J4
U$6: CONNECTION

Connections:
A: D4.4, R11.1
B: D4.3, R12.1
CLOCK: D4.6, RN1.3
CS: D4.1, RN1.4
GND: C4.2, C5.P$1, C6.P$1, D4.2, IC4.4, IC5.1, LED_DRV1:C2.P$1, LED_DRV1:IC4.2, LED_DRV1:IC4.2A, LED_DRV2:C2.P$1, LED_DRV2:IC4.2, LED_DRV2:IC4.2A, LED_DRV3:C2.P$1, LED_DRV3:IC4.2, LED_DRV3:IC4.2A, U$6.P$2
GNDD: CON2.7, CON5.7, U$6.P$1
LED_DRV1:N$2: LED_DRV1:D1.A, LED_DRV1:IC4.1, LED_DRV1:L2.1
LED_DRV2:N$2: LED_DRV2:D1.A, LED_DRV2:IC4.1, LED_DRV2:L2.1
LED_DRV3:N$2: LED_DRV3:D1.A, LED_DRV3:IC4.1, LED_DRV3:L2.1
MOSI/DATA: D4.5, RN1.2
unnamed: IC4.7, R6.2
unnamed: CATHODE1.1, LED_DRV1:L2.2
unnamed: C4.1, IC4.8, R4.1
unnamed: ANODE1.1, LED_DRV1:IC4.4, LED_DRV1:R4.P$1
unnamed: CATHODE2.1, LED_DRV2:L2.2
unnamed: CON2.4, RN1.7
unnamed: ANODE2.1, LED_DRV2:IC4.4, LED_DRV2:R4.P$1
unnamed: CON2.5, RN1.6
unnamed: CON5.4, RN2.8
unnamed: CON5.6, RN2.5
unnamed: CON5.5, RN2.7
unnamed: CON2.6, RN1.5
unnamed: CATHODE4.1, LED_DRV3:L2.2
unnamed: ANODE4.1, LED_DRV3:IC4.4, LED_DRV3:R4.P$1
PWM1: IC4.1, LED_DRV3:IC4.3
PWM2: IC4.2, LED_DRV1:IC4.3
PWM_B: IC4.3, LED_DRV2:IC4.3
RS485_A1: CON2.2, CON5.2, R12.2
RS485_B1: CON2.3, CON5.3, R11.2
VDD_5V: C6.P$2, IC5.2, IC5.4, R4.2, R6.1
VDD_12V: C5.P$2, IC5.3
VDD_24V: CON2.1, CON5.1, LED_DRV1:C2.P$2, LED_DRV1:D1.C, LED_DRV1:IC4.5, LED_DRV1:R4.P$2, LED_DRV2:C2.P$2, LED_DRV2:D1.C, LED_DRV2:IC4.5, LED_DRV2:R4.P$2, LED_DRV3:C2.P$2, LED_DRV3:D1.C, LED_DRV3:IC4.5, LED_DRV3:R4.P$2

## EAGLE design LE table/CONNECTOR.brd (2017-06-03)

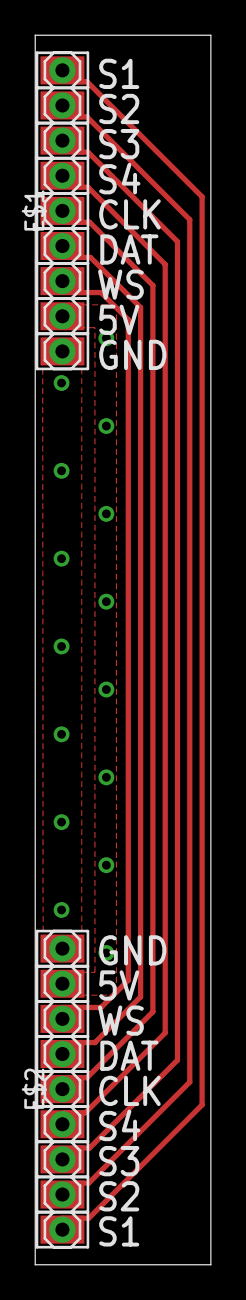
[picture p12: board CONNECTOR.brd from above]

Board: 2 copper layers, 10.0 x 70.0 mm, 4 parts (0 on the bottom side), 9 nets.

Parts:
CON1, CON3: CONNECTOR
E$1, E$2: 1X09-PTH_2

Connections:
unnamed: CON1.1, CON3.9, E$1.1, E$2.9
unnamed: CON1.2, CON3.8, E$1.2, E$2.8
unnamed: CON1.3, CON3.7
unnamed: CON1.4, CON3.6
unnamed: CON1.5, CON3.5
unnamed: CON1.6, CON3.4
unnamed: CON1.7, CON3.3
unnamed: CON1.8, CON3.2
unnamed: CON1.9, CON3.1

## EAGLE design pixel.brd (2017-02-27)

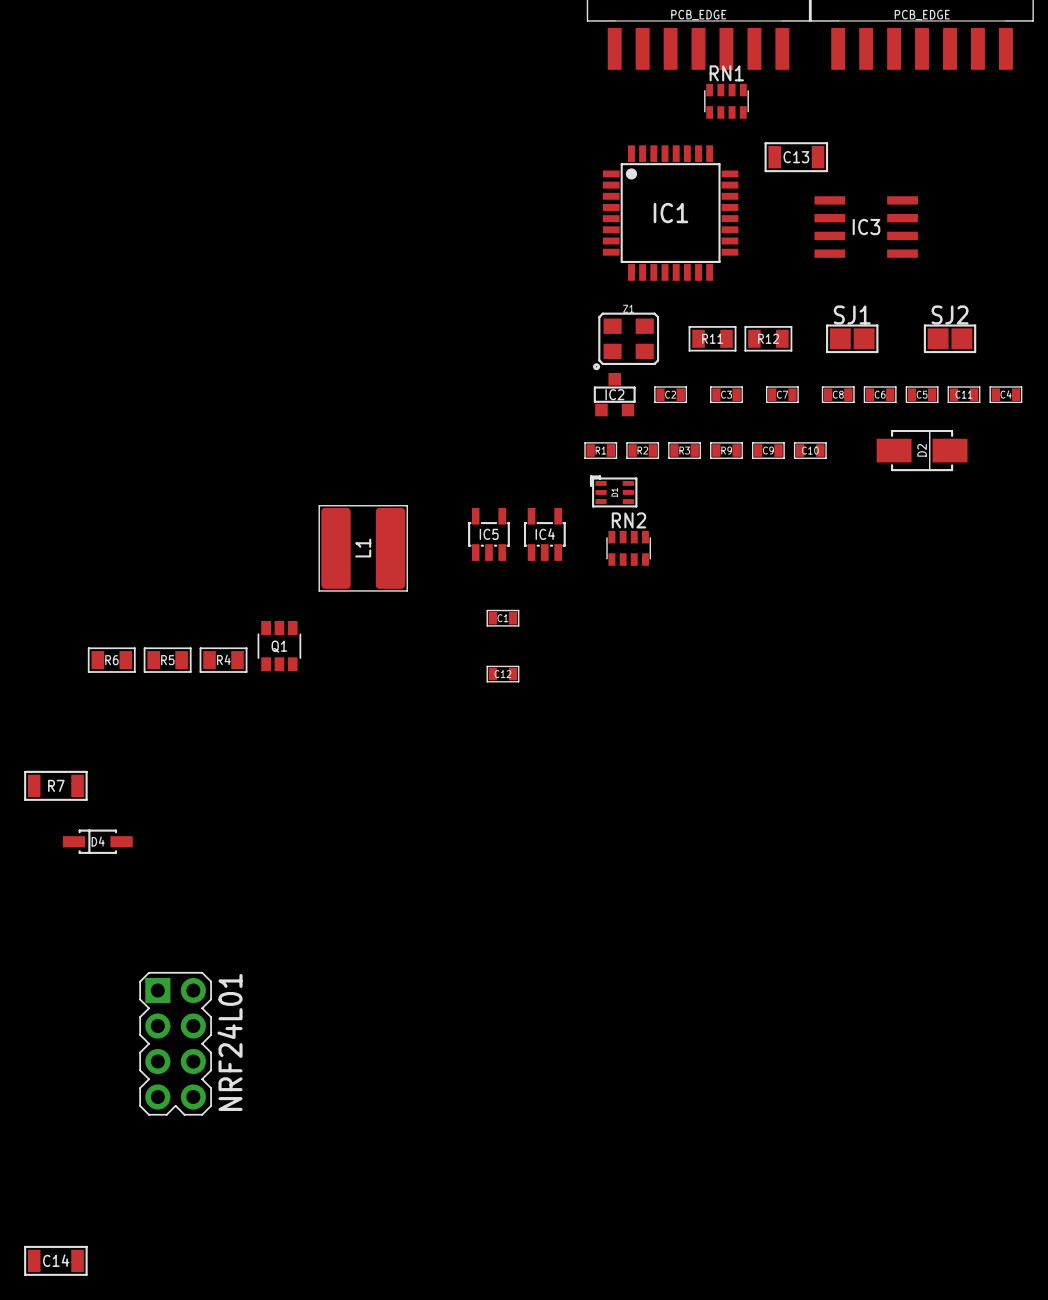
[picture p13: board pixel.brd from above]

Board: 2 copper layers, 42 parts (0 on the bottom side), 35 nets, no tracks yet.

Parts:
C1, C2, C3, C7, C8, C12: 100 nF; C0603
C4: 1 uF; C0603
C5: 10 nF; C0603
C6: 4.7 uF; C0603
C9, C10: C0603
C11: 0.1uF; C0603
C13: 1nF; C1206
C14: 10uF 6.3V; C1206
CON1, CON2: DS1066-07M-SIDE; DS1066-08M_SIDE
D1: SMF05C; SC70_6L
D2: SMAJ12A; SMA
D4: CRS08-SOD123; SOD123
IC1: STM32F030K6TX-LQFP32(7X7); LQFP32-7X7
IC2: ESDA6V1L; SOT23
IC3: ST3485SOIC8; SOIC8
IC4, IC5: MC74VHC1GT125; SOT23-5
L1: 47UH; SDR0604
NRF24L01: NRF24L01
Q1: FDC6420C; SOT23-6
R1, R9: 60R; R0603
R2, R3: 560R; R0603
R4, R5, R11, R12: 22R; R0805
R6: 10K; R0805
R7: 2R; R1206
RN1, RN2: 510R; CAT16-J4
SJ1, SJ2: RES_0
Z1: 16MHz; OSCILLATOR-3.2X2.5

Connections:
A: D2.A, IC2.2, IC3.6, R1.2, R3.2, R11.1, R11.2
B: D2.C, IC2.3, IC3.7, R2.1, R12.1, R12.2, SJ2.1
CLOCK: D1.5, IC1.22, IC4.2, RN1.2
CLOCK_BUFFERED: IC4.4, RN2.2
DATA_IN: D1.4, RN1.1
DE: IC3.2, IC3.3
GND: C1.1, C2.1, C3.1, C4.1, C5.1, C6.1, C7.1, C8.1, C9.1, C10.2, C11.1, C12.1, C13.P$2, C14.P$2, CON1.7, CON2.7, D1.2, D4.A, IC1.16, IC1.32, IC2.1, IC3.5, IC4.3, IC5.3, NRF24L01.1, Q1.5, R3.1, R7.P$1, Z1.2, Z1.4
LATCH: D1.6, IC1.21, IC5.2, RN1.3
LATCH_BUFFERED: IC5.4, RN2.3
LED1_PWM: IC1.18, R4.1
MISO: IC1.27, NRF24L01.7
MOSI: IC1.28, NRF24L01.6
unnamed: C9.2, IC1.2, Z1.1
unnamed: CON1.4, RN1.8
unnamed: C10.1, IC1.3, Z1.3
unnamed: CON1.5, RN1.7
unnamed: CON1.6, RN1.6
unnamed: CON2.4, RN2.8
unnamed: Q1.3, R5.2, R6.2
unnamed: R1.1, R9.2, SJ1.1
unnamed: CON2.5, RN2.7
unnamed: R9.1, SJ2.2
unnamed: C13.P$1, SJ1.2
unnamed: CON2.6, RN2.6
unnamed: Q1.1, R4.2
unnamed: Q1.6, R5.1
unnamed: D4.C, L1.1, Q1.2
RS485_A: CON1.2, CON2.2
RS485_B: CON1.3, CON2.3
RX: IC1.9, IC3.1
SCK: IC1.26, NRF24L01.5
TX: IC1.8, IC3.4
VDD_3V3: C1.2, C2.2, C3.2, C4.2, C5.2, C6.2, C7.2, C8.2, C11.2, C12.2, C14.P$1, IC1.1, IC1.5, IC1.17, IC3.8, IC4.5, IC5.5, NRF24L01.2, R2.2
VDD_12V: Q1.4, R6.1
VDD_24V: CON1.1, CON2.1

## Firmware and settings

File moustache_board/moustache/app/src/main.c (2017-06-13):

#include "bsp.h"
#include "Freertos.h"
#include "task.h"
#include "pwm.h"

#include "settings.h"
#include "modbus_app.h"

void blinker    (void *p);

u16 blink_period = 100;
extern modbus_app_param_t modbus_app_param ;


#define LED_DRV_FREQ    150000
#define TIMER_FREQ      48000000

#define PERIOD_TICKS TIMER_FREQ / LED_DRV_FREQ

int main(void)
{ 

  board_init();
  u32 resolution = PERIOD_TICKS;
  
  GPIO_InitTypeDef GPIO_InitStructure;
  
  GPIO_InitStructure.GPIO_Mode  = GPIO_Mode_OUT  ;
  GPIO_InitStructure.GPIO_Speed = GPIO_Speed_50MHz;
  GPIO_InitStructure.GPIO_OType = GPIO_OType_PP;
  GPIO_InitStructure.GPIO_PuPd  = GPIO_PuPd_NOPULL ;
  GPIO_InitStructure.GPIO_Pin = GPIO_Pin_10;
GPIO_Init(GPIOA, &GPIO_InitStructure);
while(1)
{
 GPIO_SetBits(GPIOA,  GPIO_Pin_10);
 for(u8 i = 0; i< 0xFF; i++){}
 GPIO_ResetBits(GPIOA,  GPIO_Pin_10);
for(u8 i = 0; i< 0xFF; i++){}
}

  
  GPIO_InitStructure.GPIO_Mode  = GPIO_Mode_AF;
  GPIO_InitStructure.GPIO_Speed = GPIO_Speed_50MHz;
  GPIO_InitStructure.GPIO_OType = GPIO_OType_PP;
  GPIO_InitStructure.GPIO_PuPd  = GPIO_PuPd_NOPULL ;
  
  GPIO_InitStructure.GPIO_Pin = GPIO_Pin_10;
  GPIO_Init(GPIOA, &GPIO_InitStructure);
  GPIO_PinAFConfig(GPIOA, GPIO_PinSource10, GPIO_AF_2); 


  TIM_TimeBaseInitTypeDef  TIM_TimeBaseStructure;
  TIM_OCInitTypeDef  TIM_OCInitStructure;
  TIM_Cmd(TIM1, DISABLE); 
 
  TIM_TimeBaseStructure.TIM_Prescaler           = 0;
  TIM_TimeBaseStructure.TIM_CounterMode         = TIM_CounterMode_Up;
  TIM_TimeBaseStructure.TIM_Period              = PERIOD_TICKS;
  TIM_TimeBaseStructure.TIM_ClockDivision       = 0;
  TIM_TimeBaseStructure.TIM_RepetitionCounter   = 0;

  TIM_TimeBaseInit(TIM1, &TIM_TimeBaseStructure);

  TIM_OCInitStructure.TIM_OCMode        = TIM_OCMode_PWM2;
  TIM_OCInitStructure.TIM_OutputState   = TIM_OutputState_Enable;
  TIM_OCInitStructure.TIM_Pulse         = 0;
  TIM_OCInitStructure.TIM_OCPolarity    = TIM_OCPolarity_Low;
  TIM_OCInitStructure.TIM_OCIdleState   = TIM_OCIdleState_Set;
    
  TIM_OC3Init(TIM1, &TIM_OCInitStructure);
  
  TIM_Cmd(TIM1, ENABLE);
  TIM_CtrlPWMOutputs(TIM1, ENABLE);
  
  TIM_SetCompare3(TIM1, PERIOD_TICKS);  

  while(1){}
  
  
  xTaskCreate(blinker,                    /* Function that implements the task. */
              "blink",                    /* Name */
              configMINIMAL_STACK_SIZE,   /* Stack size in words, not bytes. */
              ( void * ) &blink_period,   /* Parameter passed into the task. */
              tskIDLE_PRIORITY + 1,       /* Priority at which the task is created. */
              NULL );  


//  xTaskCreate(modbus_app,                     /* Function that implements the task. */
//              "modbus",                       /* Name */
//              configMINIMAL_STACK_SIZE * 2,   /* Stack size in words, not bytes. */
//              ( void * ) &modbus_app_param,   /* Parameter passed into the task. */
//              tskIDLE_PRIORITY + 1,           /* Priority at which the task is created. */
//              NULL );  
  
  vTaskStartScheduler();
}



void blinker(void *p)
{

while(1)
{
LED_toggle();  
vTaskDelay( 100 / portTICK_PERIOD_MS );
}
}

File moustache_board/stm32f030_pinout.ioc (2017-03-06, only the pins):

Mcu.UserName=STM32F030K6Tx
PA0.Signal=ADC_IN0
PA1.Signal=USART1_DE
PA10.Signal=S_TIM1_CH3
PA13.Signal=SYS_SWDIO
PA14.Signal=SYS_SWCLK
PA15.Signal=SPI1_NSS
PA2.Signal=USART1_TX
PA3.Signal=USART1_RX
PA4.Signal=ADC_IN4
PA5.Signal=ADC_IN5
PA6.Signal=ADC_IN6
PA8.Signal=S_TIM1_CH1
PA9.Signal=S_TIM1_CH2
PB3.Signal=SPI1_SCK
PB5.Signal=SPI1_MOSI
PF0-OSC_IN.Signal=RCC_OSC_IN
PF1-OSC_OUT.Signal=RCC_OSC_OUT

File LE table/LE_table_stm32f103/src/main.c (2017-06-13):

#include "bsp.h"
#include "FreeRTOS.h"
#include "task.h"
#include "queue.h"
#include <stdlib.h>


#include "ver.h"
#include <stdio.h>
#include <string.h>
#include "types.h"
#include "le_table.h"

#define FRAME_LEN       32
#define DELAY_MS        2


void _delay_ms(u32 d);
void ADC_DMA_init(void);
  ws2812_t frame[FRAME_LEN] = {0};
  void frame_update(void);

  u8 flagster = 1;
  int main(void)
{
  SystemInit();
  board_init();
  SysTick_Config(72000);

  ADC_DMA_init();
   while(1)
  {   
    sensor_poll();
  //  frame_update();
  //  ws2812_send(frame,FRAME_LEN);
    }
  }


static u8 flag[FRAME_LEN] = {0};

u32 uptime = 0;
void _delay_ms(u32 d)
{
  d +=uptime;
  while(uptime < d){}
}

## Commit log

2017-02-20 initial import
    [pwm_controller.brd, pwm_controller.sch]
2017-02-25 added STM32F030K6T6
2017-02-26 MCU replaced with STM32F030K6T6
    [stm32f030_pinout.ioc]
2017-02-26 First step
    [pixel.brd, pixel.sch]
2017-02-26 Diodes library
2017-02-26 Preliminary LED driver
    [pixel.brd, pixel.sch]
2017-02-27 minor changes
    [pixel.brd, pixel.sch]
2017-02-28 added PT4115 reference board
    [PT4115-Driver.brd, PT4115-Driver.sch, pwm_controller.brd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]
2017-02-28 naming fixes pixel8 initial import
    [pixel32.brd, pixel32.sch, pixel8.brd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]
2017-03-01 -added DC-DC
    [pixel32.brd, pixel32.sch]
2017-03-01 Led driver schematics added
    [pixel32.brd, pixel32.sch]
2017-03-01 SOT-23 P and N chanel MOSFETs added
2017-03-01 LED driver updated
    [pixel32.brd, pixel32.sch]
2017-03-02 pcb attmepts
    [pixel32.brd, pixel32.sch]
2017-03-04 pixelD added
    [pixelD.brd, pixelD.sch]
2017-03-04 First attempts in routing the PCB
    [pixel32.brd, pixel32.sch]
2017-03-05 First attempts in routing
    [pixel32.brd, pixel32.sch]
2017-03-06 LED Driver
2017-03-07 All devices have been imported to the libraries
2017-03-11 PCB finalization
    [pixel32.brd, pixel32.sch]
2017-03-12 pixel8 update
    [pixel8.brd, pixel8.sch]
2017-03-12 pixelD update
    [pixelD.brd, pixelD.sch]
2017-03-12 some tmp files added
    [pixel32.brd, pixel32.sch]
2017-03-12 RTU preliminary frames
2017-03-12 RTU logo on silkscreen
2017-03-12 PCB Finalization #2
    [pixel32.brd, pixel32.sch]
2017-03-13 32 ver 3dview added
    [pixel8.brd]
2017-03-13 -pixel32 update
    [pixel32.brd, pixel32.sch]
2017-03-14 -more edge connectors
    [pixel32.brd, pixel32.sch]
2017-03-15 voltage regulator recalculated, minor fixes, attributes
    [pixel32.brd, pixel32.sch]
2017-03-15 input sense divider values added boot0 fix
    [pixel32.brd, pixel32.sch]
2017-03-15 TME part numbers added
    [pixel32.brd, pixel32.sch]
2017-03-15 added reset pad
    [pixel32.brd, pixel32.sch, pixel8.brd]
2017-03-15 Reset pad routing, clearance error resolving
    [pixel32.brd, pixel32.sch]
2017-03-16 Preliminary BOM
    [pixel32_BOM.xlsx]
2017-03-16 minor fixes
    [pixel32.brd]
2017-03-16 minor updates
    [pixel32.brd, pixel32.sch]
2017-03-17 Added spare power connector just in case. New 3d view.
    [pixel32.brd, pixel32.sch]
2017-03-17 RTU logo removed
    [pixel32.brd]
2017-03-17 Moustashe added
    [pixel32.brd, pixel32.sch]
2017-03-17 naming fixes minor silk fixes
    [moustache_board.brd, moustache_board.sch, pixel32.brd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]
2017-03-17 -directories reorganisation added gerbers for moustache board
    [moustache_board.brd, moustache_board.sch, pixel32.brd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]
2017-03-17 PCB Stencil added
2017-04-03 BOM update
    [pixel32_BOM.xlsx]
2017-04-22 Another Brick In the Wall initial import
    [ABITW.brd, ABITW.sch]
2017-04-22 Le table initial import
    [moustache_board.brd, moustache_board.sch]
2017-05-02 -LE TABLE completed
    [CONNECTOR.brd, PCB.skp, connector.skp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]
2017-06-13 Software import
    [BOM.ods, le_table.brd, le_table.csv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]

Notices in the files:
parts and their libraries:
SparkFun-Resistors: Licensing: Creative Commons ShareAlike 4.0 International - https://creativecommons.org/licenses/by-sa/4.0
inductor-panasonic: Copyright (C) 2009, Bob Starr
